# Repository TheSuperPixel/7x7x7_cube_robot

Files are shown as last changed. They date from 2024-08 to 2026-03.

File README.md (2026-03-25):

# 7x7x7_cube_robot
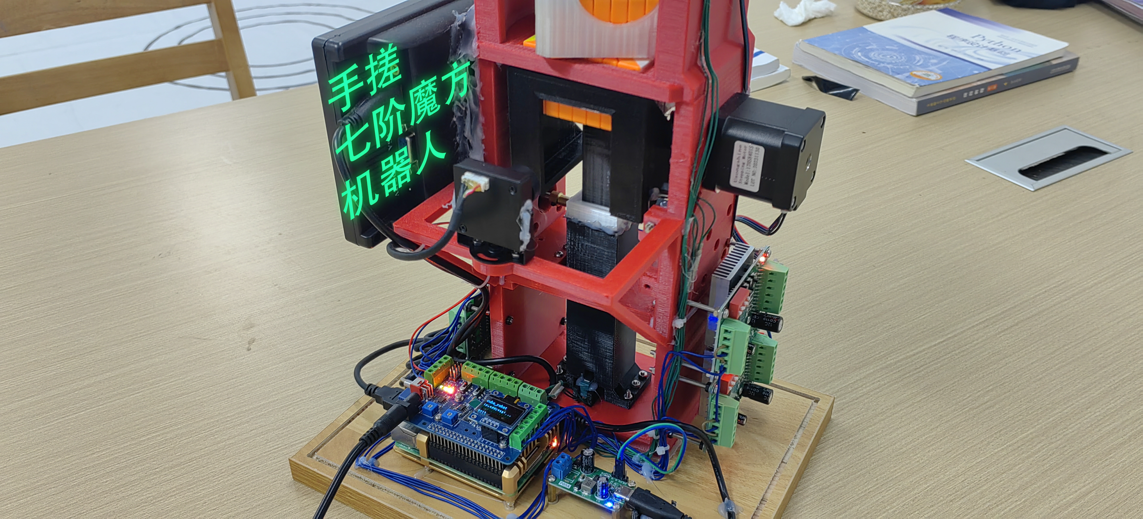
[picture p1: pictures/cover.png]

#### 介绍
使用树莓派控制的魔方机器人，可以在平均20分钟的时间内完成7阶魔方的还原。
这个工程的主要部分复刻了B站“爱跑步的小何”的七阶魔方机器人开源工程，但是在这个工程的基础上，使用了网上开源的CIEDE2000颜色算法识别魔方颜色，提升的颜色识别准确度，另外参照网上开源的OLED程序，额外移植并编写了Linux的OLED、LED和按键的设备驱动，编写了用户菜单界面，使得机器人通电后无需联网、键盘和鼠标，使用按钮进入菜单即可让装置单机还原魔方。<br>
使用C + Python开发，含有结构设计、软件部分，演示视频。推荐使用树莓派4B 4GB，已经通过测试<br>
工程代码添加了部分注释，有些是当时在阅读项目原作者代码时留下来的笔记，因为本人只是电子类大二的学生，Python，Linux，Opencv，Pcb等全部都是提前自学的，项目难免会有缺陷和问题，如果项目出现运行错误，可以参考项目原作者和参考开源项目的readme文件，期待大佬们的宝贵建议
#### 项目主要参考开源资料：
1.七阶魔方机器人源程序：https://gitee.com/hemn1990/cube_robot_7x7x7<br>
2.qbr颜色识别：https://github.com/kkoomen/qbr<br>
3.高阶魔方求解算法：https://github.com/dwalton76/rubiks-cube-NxNxN-solver<br>
4.三阶魔方求解算法：https://github.com/dwalton76/kociemba<br>
5.OLED程序：https://gitee.com/oldzhai/stc89c51/tree/master/oled_i2c

#### 系统架构
```
12V电源--12V转5V电源模块--树莓派--+--步进电机驱动器(TB6560)--升降控制电机(42步进电机)
                                +--升降零点微动开关
                                |
                                +--步进电机驱动器(TB6560)--翻转控制电机(42步进电机)
                                +--翻转零点光电开关
                                |
                                +--步进电机驱动器(TB6560)--旋转控制电机(42步进电机)	
                                +--旋转零点光电开关
                                |
                                +--OLED显示屏，五向摇杆开关(用于脱机运行，OLED显示菜单，摇杆开关用于切换功能)
                                |
                                +--USB摄像头（120度视角）
                                +--键盘、鼠标、显示器
```                         

#### 演示视频：
【树莓派自制支持离线单机复原七阶魔方机器人】 https://www.bilibili.com/video/BV1At42157M8

#### 配置与运行步骤：
1、克隆项目到/home/pi/Desktop/,这个项目里面的文件编译链接，Makefile编写是使用绝对路径的，因此项目运行的路径是被固定的

2、安装python3-opencv
``` 
sudo apt-get install python3-opencv
```
3、安装ckociemba
``` 
cd cube_project\kociemba-develop\kociemba\ckociemba
make clean
make
sudo make install
``` 
3、安装rubiks-cube-NxNxN-solver（该版本相对于原始版本有修改，通过文件流把求解结果传送到cube_robot_motion.py进行运行）
``` 
cd \cube_project\rubiks-cube-NxNxN-solver-master
make clean
make init
./rubiks-cube-solver.py --state DBDBDDFBDDLUBDLFRFRBRLLDUFFDUFRBRDFDRUFDFDRDBDBULDBDBDBUFBUFFFULLFLDURRBBRRBRLFUUUDUURBRDUUURFFFLRFLRLDLBUFRLDLDFLLFBDFUFRFFUUUFURDRFULBRFURRBUDDRBDLLRLDLLDLUURFRFBUBURBRUDBDDLRBULBULUBDBBUDRBLFFBLRBURRUFULBRLFDUFDDBULBRLBUFULUDDLLDFRDRDBBFBUBBFLFFRRUFFRLRRDRULLLFRLFULBLLBBBLDFDBRBFDULLULRFDBR
``` 
第二个步骤很慢，需要联网下载大量查找表，解压后需要占用数G空间。

4、编译并且加载内核模块，在此之前请安装好linux内核头文件，安装位置可参照Makefile
``` 
cd cube_project\cube_robot_7x7x7-master\cube_robot_kernel_module
make clean
make
sudo make load
cd ..
``` 
如需调整电机旋转速度，修改step_moter.py，make table后重新编译内核模块

6、运行主程序
``` 
cd cube_project
sudo run.sh
``` 
1.由于lunch.py使用了subprocess来获取IP信息并且打印在OLED屏幕上，因此如果设备未联网，可能会造成程序卡死或报错，如果无网络，可以将获取IP信息的代码注释，即可正常运行<br>
2.运行后，OLED屏幕会显示菜单，使用五向开关来移动光标和选择选项。在主菜单中，选择“Solve!”进入还原模式，等待出现预览画面后，放入魔方，向右推动摇杆或按下空格键开始还原魔方，向上推动摇杆或按下键盘的'c'键开始进行魔方颜色校准，在校准模式下，向下推动摇杆或按下键盘的空格键校准下一个面的颜色。<br>
3.魔方在转动过程中可能会出现卡顿现象，魔方可能会掉出，需要用手推回去，推测可能是因为3D打印结构缺陷引起<br>
4.魔方颜色识别阈值信息被存储在/home/pi/.config/qbr/settings.json内，如果报错“找不到此文件”，可以尝试在同目录下创建一个同名空文件

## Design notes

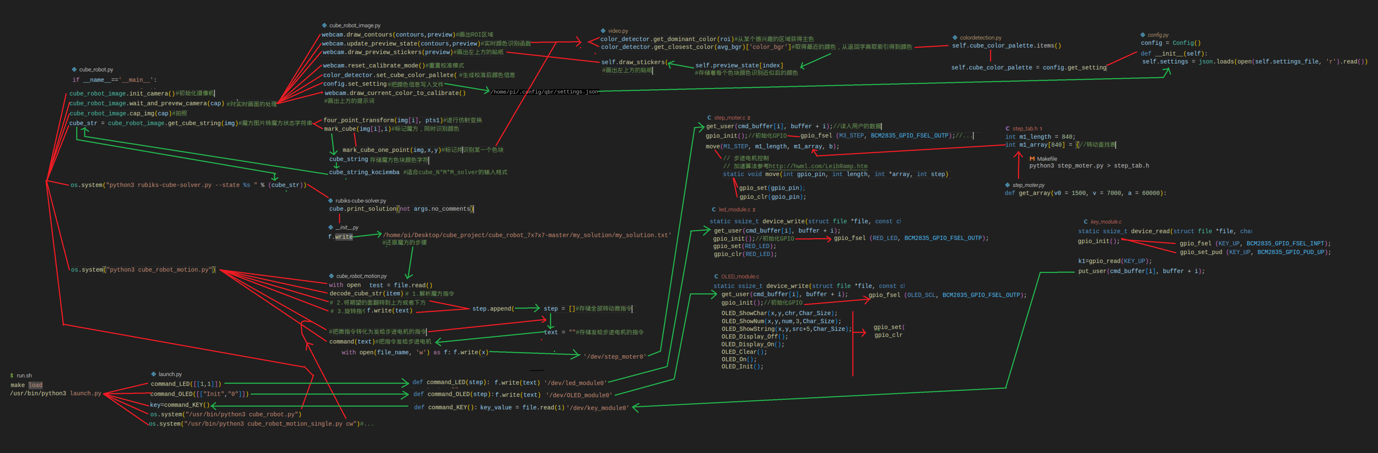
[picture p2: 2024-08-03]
七阶魔方机器人代码框图.png

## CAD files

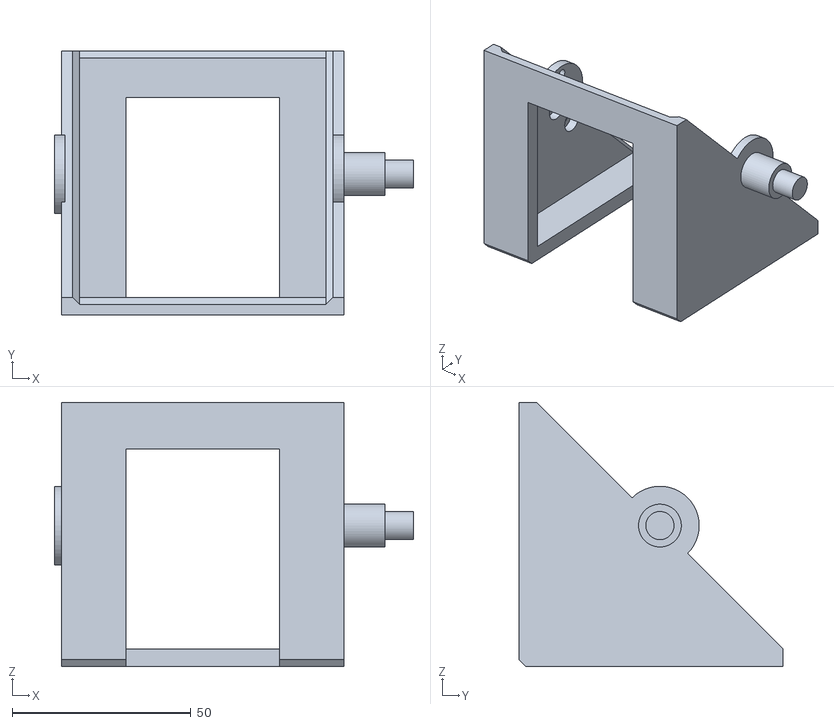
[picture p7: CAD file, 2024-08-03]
结构图/翻转架修改.STL
100.5 x 74.0 x 74.0

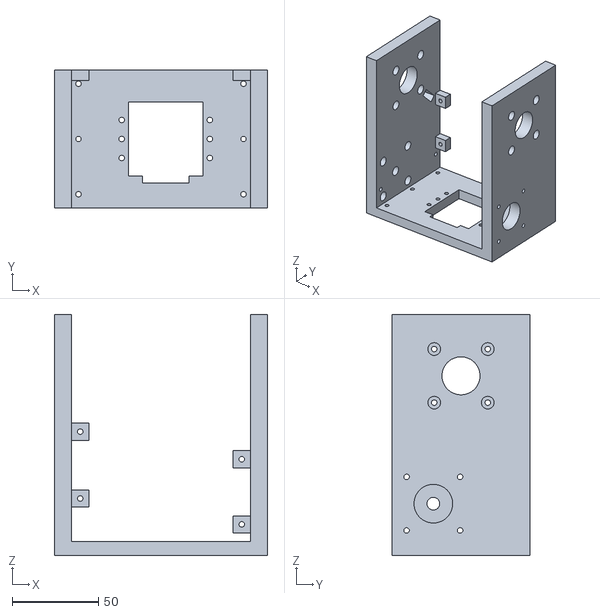
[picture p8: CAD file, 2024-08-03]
结构图/上层框架partA.STL
123.5 x 80.0 x 139.5

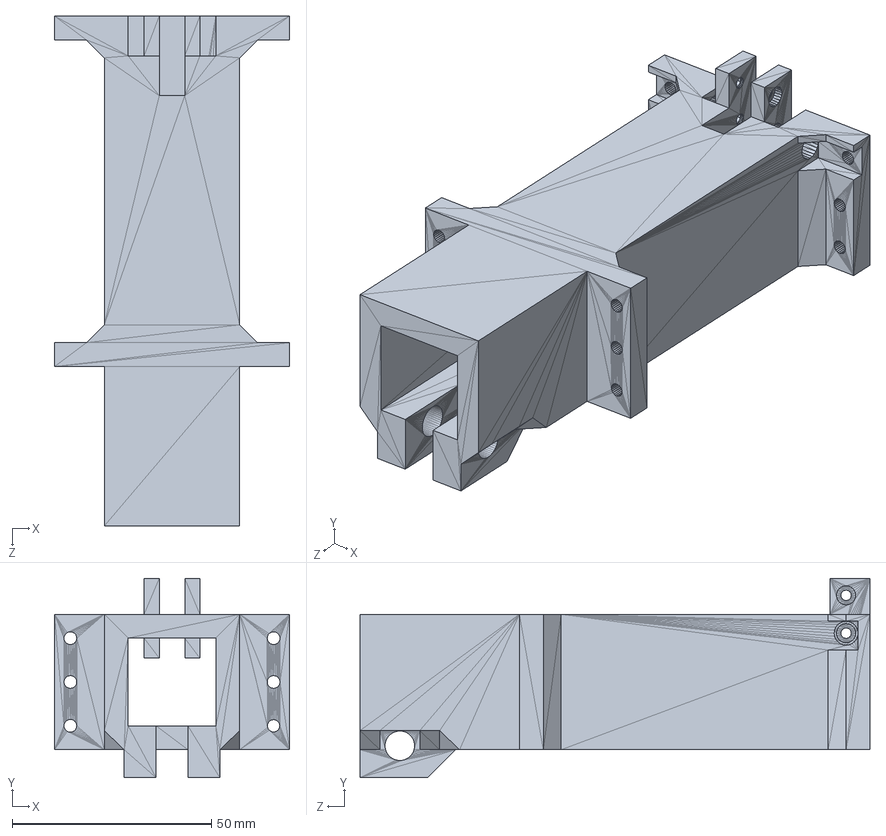
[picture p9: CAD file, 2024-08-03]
结构图/升降杆套筒.SLDPRT
59.0 x 50.0 x 128.0 mm

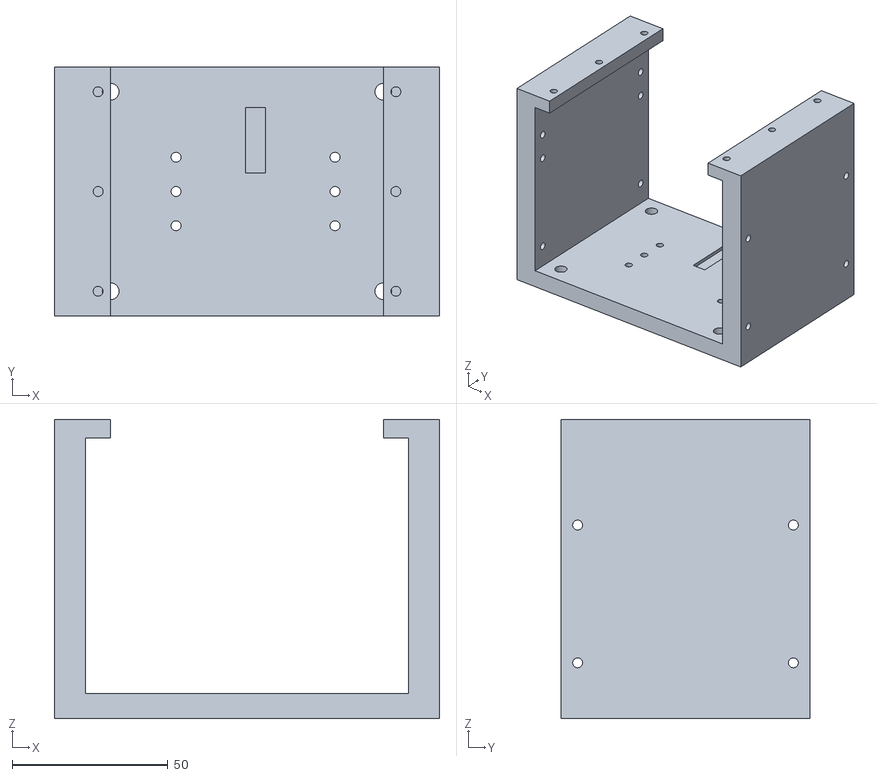
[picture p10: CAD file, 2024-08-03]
结构图/下层框架.stl
123.5 x 80.0 x 96.0

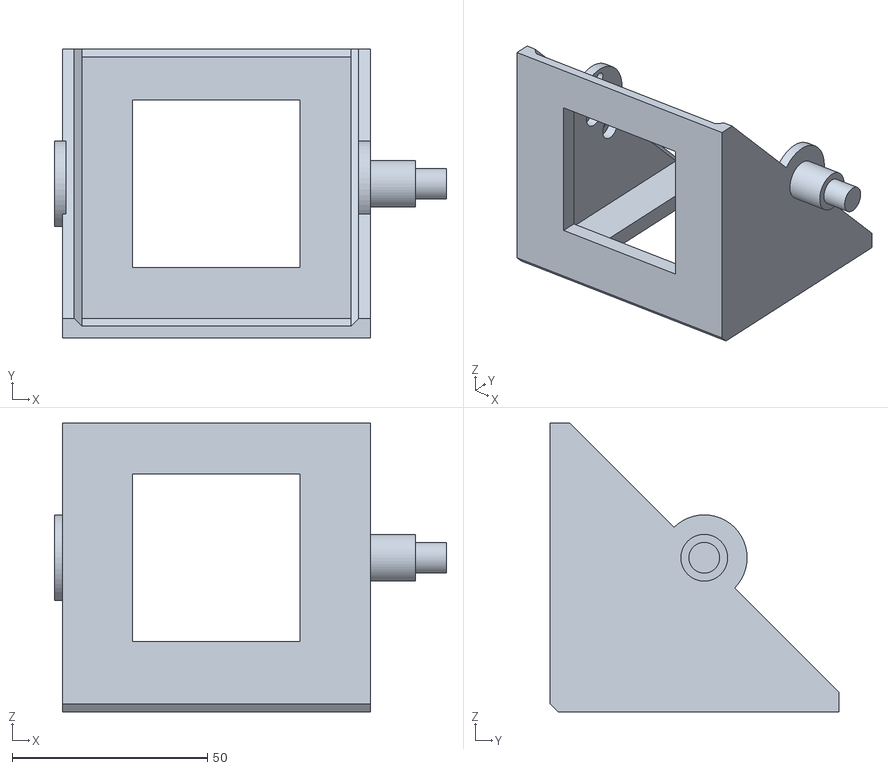
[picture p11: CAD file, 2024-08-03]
结构图/翻转架.stl
100.5 x 74.0 x 74.0

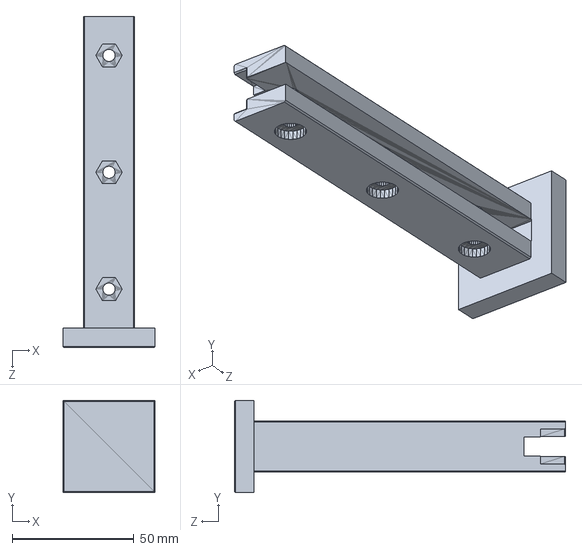
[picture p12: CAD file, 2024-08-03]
结构图/升降杆_打磨.SLDPRT
38.0 x 38.0 x 136.0 mm

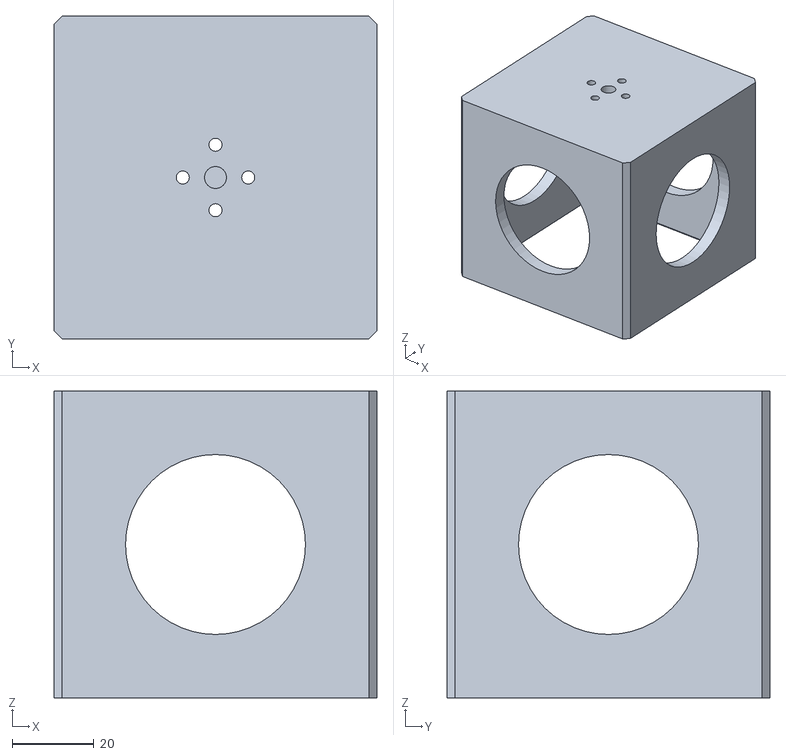
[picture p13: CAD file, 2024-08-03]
结构图/魔方笼.stl
79.0 x 79.0 x 75.0

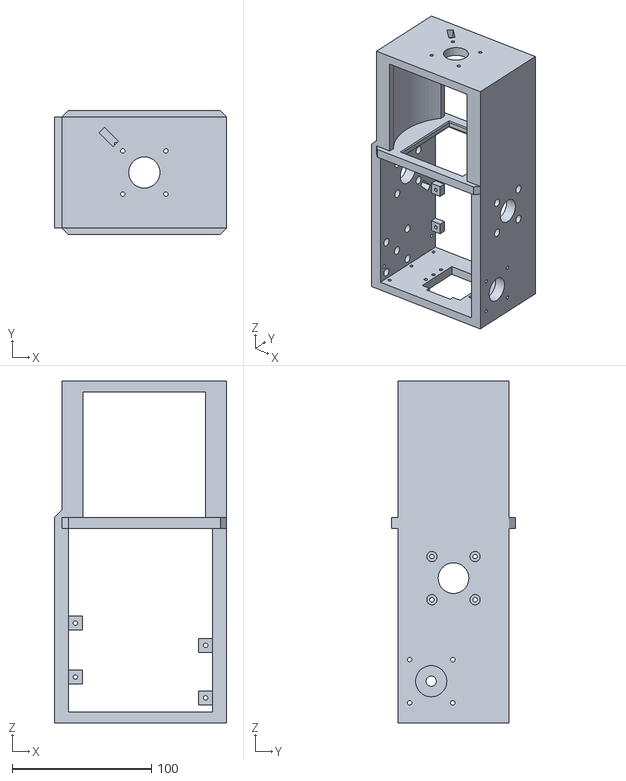
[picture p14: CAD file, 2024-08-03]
结构图/上层框架.stl
123.5 x 89.0 x 245.5

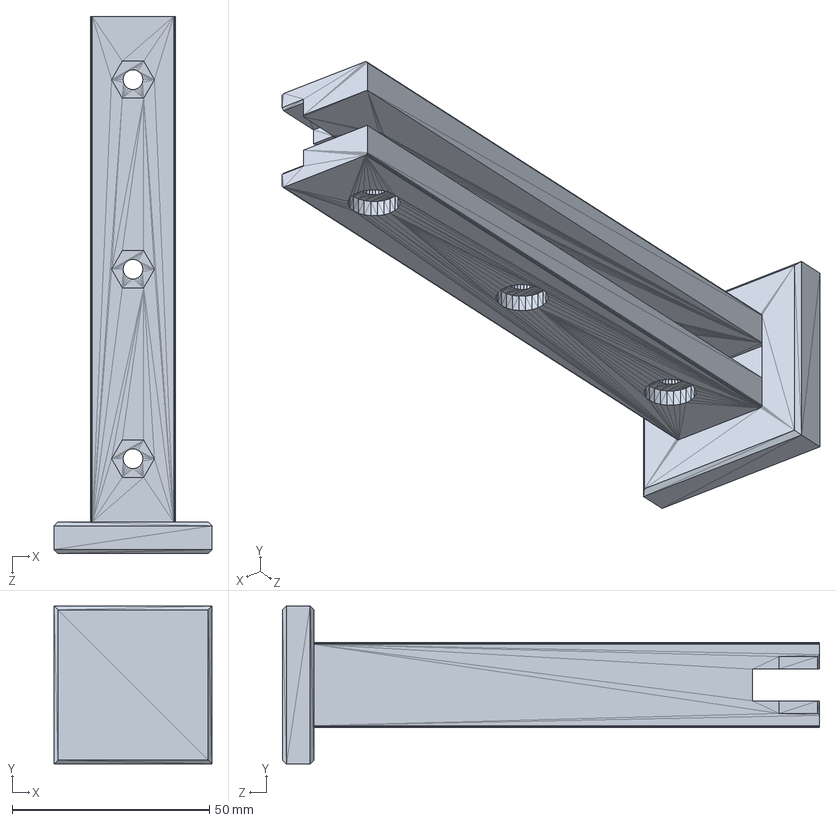
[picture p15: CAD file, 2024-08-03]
结构图/升降杆.SLDPRT
40.0 x 40.0 x 136.0 mm

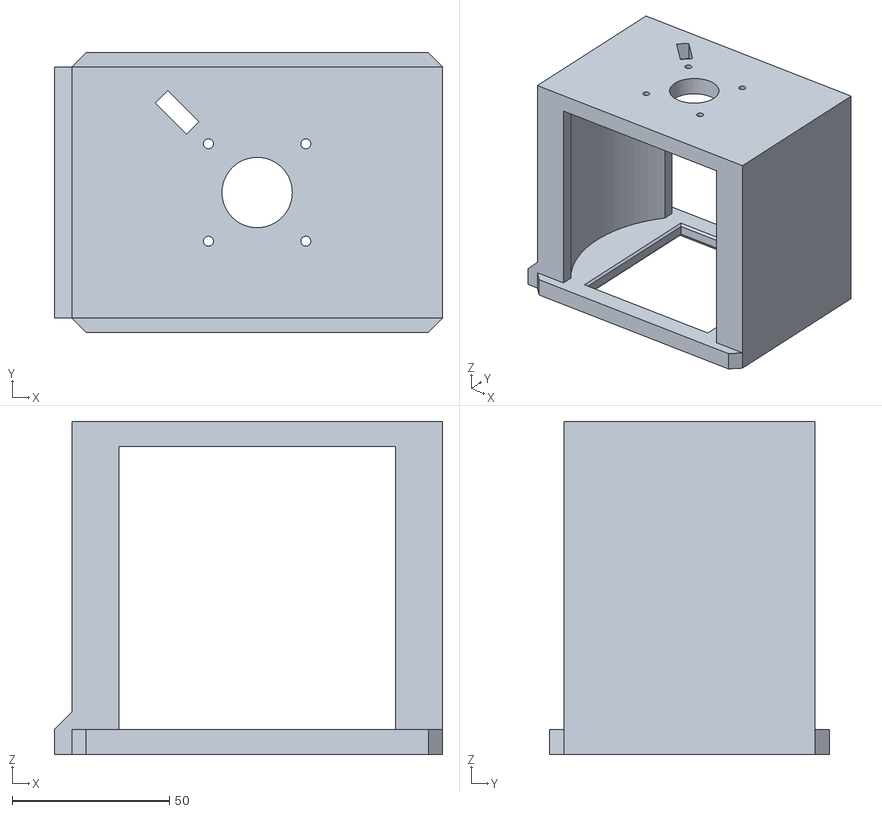
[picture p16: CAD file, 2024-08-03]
结构图/上层框架partB.STL
123.5 x 89.0 x 106.0

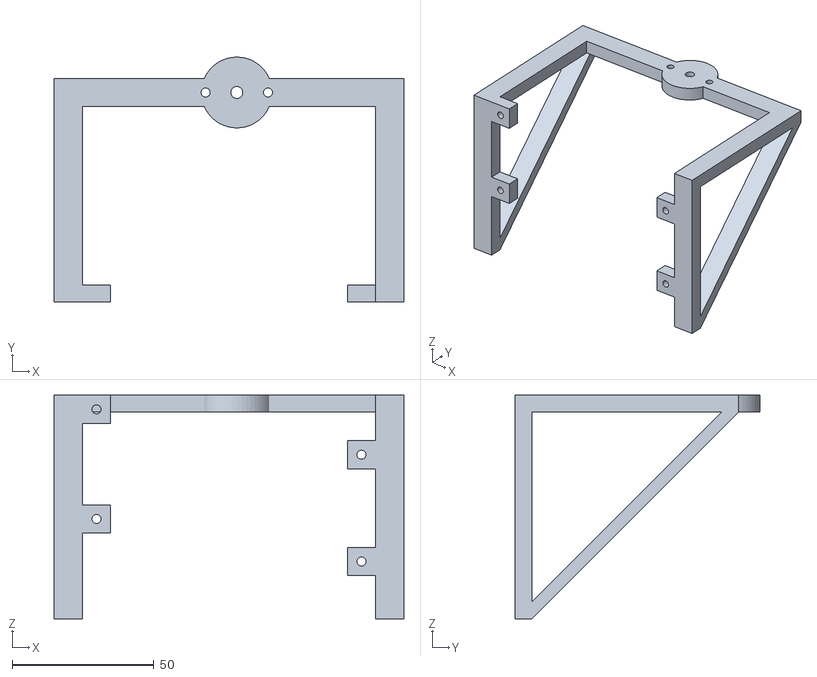
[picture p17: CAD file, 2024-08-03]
结构图/摄像头支架.stl
123.5 x 86.4 x 78.9

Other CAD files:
结构图/升降杆.stl
结构图/升降杆_打磨.STL
结构图/升降杆套筒.stl
结构图/魔方机器人（七阶）.skp

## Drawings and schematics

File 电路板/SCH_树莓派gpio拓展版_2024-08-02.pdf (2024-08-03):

# U4.1 GND ³.3V

# U6.1 GND ³.3V

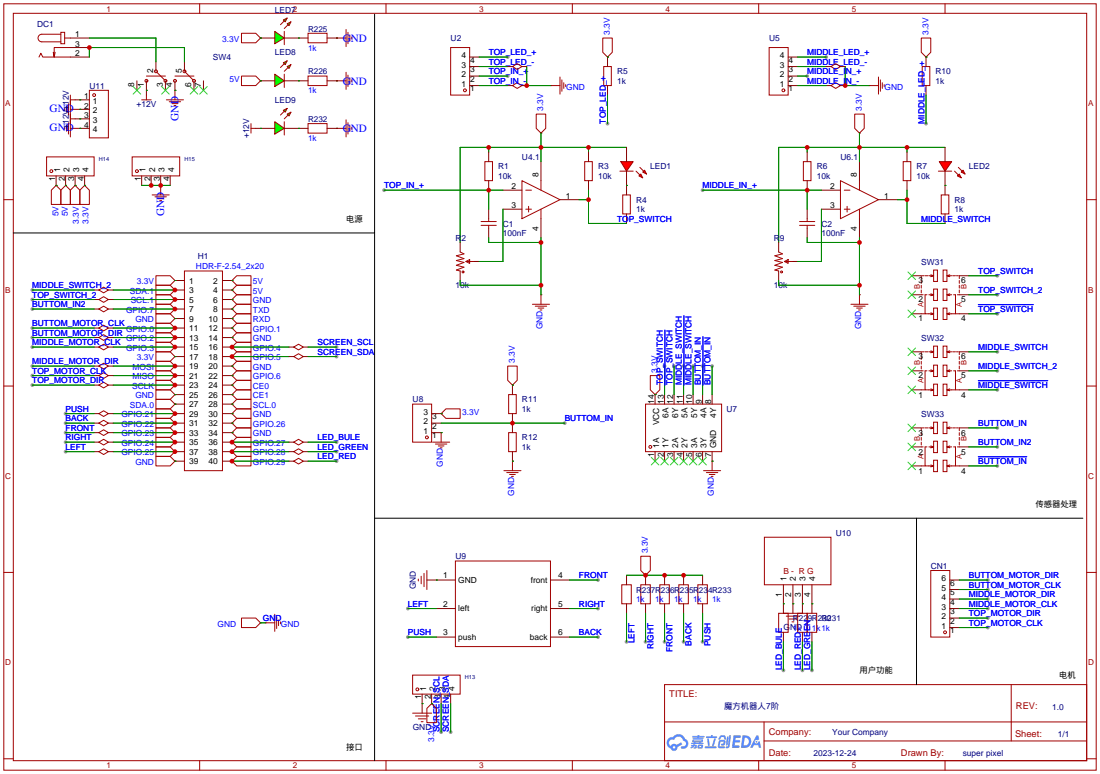
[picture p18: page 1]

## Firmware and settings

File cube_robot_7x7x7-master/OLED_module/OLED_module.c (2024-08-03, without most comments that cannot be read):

#include <linux/module.h>
#include <linux/kernel.h>
#include <linux/init.h>
#include <asm/delay.h>
#include <asm/io.h>
//#include <linux/slab.h> 
#include <linux/fs.h>
#include <asm/uaccess.h>    /* for put_user */
#include <linux/cdev.h>
#include <linux/errno.h>
#include <asm/current.h>
#include <linux/sched.h>
#include <linux/device.h>

#include "OLED_module.h"
#include "oledfont.h"
MODULE_LICENSE("GPL"); 
MODULE_VERSION("0.1"); 
/*
输入：   command,data

command			data
-------------------------------------------------------------------------			
ShowChar		格式：xxyyzw	x：x坐标 y：y坐标 z：字符 w：字体大小 0/1
ShowNum			格式：xxyyzzzw	x：x坐标 y：y坐标 zzz：三位数 w：字体大小 0/1
ShowString		格式：xxyywsss...		x：x坐标 y：y坐标 w：字体大小 0/1 s:字符串
ShowCHinese		不支持
DrawBMP			不支持
DisplayOff		0
DisplayOn		0
Clear			0
On				0
Init			0
*/
static uint32_t* gpio_base = 0;

/* Read input pin */
static uint8_t gpio_read(uint8_t pin)
{
    volatile uint32_t* paddr = gpio_base + BCM2835_GPLEV0/4 + pin/32;
    uint8_t shift = pin % 32;
    uint32_t value = ioread32(paddr);
    return (value & (1 << shift)) ? HIGH : LOW;
}

/* Set output pin */
static void gpio_set(uint8_t pin)
{
    volatile uint32_t* paddr = gpio_base + BCM2835_GPSET0/4 + pin/32;
    uint8_t shift = pin % 32;
    iowrite32(1 << shift, paddr);
}

/* Clear output pin */
static void gpio_clr(uint8_t pin)
{
    volatile uint32_t* paddr = gpio_base + BCM2835_GPCLR0/4 + pin/32;
    uint8_t shift = pin % 32;
    iowrite32(1 << shift, paddr);
}

/* Set the pullup/down resistor for a pin */
static void gpio_set_pud(uint8_t pin, uint8_t pud)
{
        int shiftbits = (pin & 0xf) << 1;
        uint32_t bits;
        uint32_t pull;
        volatile uint32_t* paddr;
        switch (pud)
        {
           case BCM2835_GPIO_PUD_OFF:  pull = 0; break;
           case BCM2835_GPIO_PUD_UP:   pull = 1; break;
           case BCM2835_GPIO_PUD_DOWN: pull = 2; break;
           default: return;
        }
        paddr = gpio_base + BCM2835_GPPUPPDN0/4 + (pin >> 4);
        
        bits = ioread32( paddr );
        bits &= ~(3 << shiftbits);
        bits |= (pull << shiftbits);
        iowrite32(bits, paddr);
}

/* set gpio input or output mode */
static void gpio_fsel(uint8_t pin, uint8_t mode)
{
    /* Function selects are 10 pins per 32 bit word, 3 bits per pin */
    volatile uint32_t* paddr = gpio_base + BCM2835_GPFSEL0/4 + (pin/10);
    uint8_t   shift = (pin % 10) * 3;
    uint32_t  mask = BCM2835_GPIO_FSEL_MASK << shift;
    uint32_t  value = mode << shift;
    
    uint32_t v = ioread32(paddr);
    v = (v & ~mask) | (value & mask);
    iowrite32(v, paddr);
}

void OLED_SCLK_Set(void){
	gpio_set(OLED_SCL);
	udelay(1);
}
void OLED_SCLK_Clr(void){
	gpio_clr(OLED_SCL);
	udelay(1);
}
void OLED_SDIN_Clr(void){
	gpio_clr(OLED_SDA);
	udelay(1);
}
void OLED_SDIN_Set(void){
	gpio_set(OLED_SDA);
	udelay(1);
}
/***********************Delay****************************************/
void Delay_50ms(unsigned int Del_50ms)
{
	unsigned int m;
	for(m=0;m<50;m++){
		udelay(1000);
	}
}

void Delay_1ms(unsigned int Del_1ms)
{
	udelay(1000);
}


/**********************************************
//IIC Start
**********************************************/
void IIC_Start(void)
{
	OLED_SCLK_Set() ;
	OLED_SDIN_Set();
	OLED_SDIN_Clr();
	OLED_SCLK_Clr();
}

/**********************************************
//IIC Stop
**********************************************/
void IIC_Stop(void)
{
	OLED_SCLK_Set() ;
	OLED_SDIN_Clr();
	OLED_SDIN_Set();
}

void IIC_Wait_Ack(void)
{
	OLED_SCLK_Set() ;
	OLED_SCLK_Clr();
}
/**********************************************
// IIC Write byte
**********************************************/

void Write_IIC_Byte(unsigned char IIC_Byte)
{
	unsigned char i;
	unsigned char m,da;
	da=IIC_Byte;
	OLED_SCLK_Clr();
	for(i=0;i<8;i++)		
	{
			m=da;
		//	OLED_SCLK_Clr();
		m=m&0x80;
		if(m==0x80)
		{OLED_SDIN_Set();}
		else OLED_SDIN_Clr();
			da=da<<1;
		OLED_SCLK_Set();
		OLED_SCLK_Clr();
		}
}

/**********************************************
// IIC Write Command
**********************************************/
void Write_IIC_Command(unsigned char IIC_Command)
{
   IIC_Start();
   Write_IIC_Byte(0x78);            //Slave address,SA0=0
	IIC_Wait_Ack();	
   Write_IIC_Byte(0x00);			//write command
	IIC_Wait_Ack();	
   Write_IIC_Byte(IIC_Command); 
	IIC_Wait_Ack();	
   IIC_Stop();
}
/**********************************************
// IIC Write Data
**********************************************/
void Write_IIC_Data(unsigned char IIC_Data)
{
   IIC_Start();
   Write_IIC_Byte(0x78);			//D/C#=0; R/W#=0
	 IIC_Wait_Ack();	
   Write_IIC_Byte(0x40);			//write data
	 IIC_Wait_Ack();	
   Write_IIC_Byte(IIC_Data);
	 IIC_Wait_Ack();	
   IIC_Stop();
}
void OLED_WR_Byte(unsigned dat,unsigned cmd)
{
	if(cmd)
	{
		Write_IIC_Data(dat);
	}
	else 
	{	
		Write_IIC_Command(dat);
	}
}

/********************************************
// fill_Picture
********************************************/
void fill_picture(unsigned char fill_Data)
{
	unsigned char m,n;
	for(m=0;m<8;m++)
	{
		OLED_WR_Byte(0xb0+m,0);		//page0-page1
		OLED_WR_Byte(0x00,0);		//low column start address
		OLED_WR_Byte(0x10,0);		//high column start address
		for(n=0;n<128;n++)
			{
				OLED_WR_Byte(fill_Data,1);
			}
	}
}



void OLED_Set_Pos(unsigned char x, unsigned char y) 
{ 	OLED_WR_Byte(0xb0+y,OLED_CMD);
	OLED_WR_Byte(((x&0xf0)>>4)|0x10,OLED_CMD);
	OLED_WR_Byte((x&0x0f),OLED_CMD); 
} 


void OLED_Display_On(void)
{
	OLED_WR_Byte(0X8D,OLED_CMD);
	OLED_WR_Byte(0X14,OLED_CMD);  //DCDC ON
	OLED_WR_Byte(0XAF,OLED_CMD);  //DISPLAY ON
}


void OLED_Display_Off(void)
{
	OLED_WR_Byte(0X8D,OLED_CMD);
	OLED_WR_Byte(0X10,OLED_CMD);  //DCDC OFF
	OLED_WR_Byte(0XAE,OLED_CMD);  //DISPLAY OFF
}


void OLED_Clear(void)  
{  
	u8 i,n;		    
	for(i=0;i<8;i++)  
	{  
		OLED_WR_Byte (0xb0+i,OLED_CMD);
		OLED_WR_Byte (0x00,OLED_CMD);
		OLED_WR_Byte (0x10,OLED_CMD);
		for(n=0;n<128;n++)OLED_WR_Byte(0,OLED_DATA); 
	}
}

void OLED_On(void)  
{  
	u8 i,n;		    
	for(i=0;i<8;i++)  
	{  
		OLED_WR_Byte (0xb0+i,OLED_CMD);
		OLED_WR_Byte (0x00,OLED_CMD);
		OLED_WR_Byte (0x10,OLED_CMD);
		for(n=0;n<128;n++)OLED_WR_Byte(1,OLED_DATA); 
	}
}


//x:0~127
//y:0~63


void OLED_ShowChar(u8 x,u8 y,u8 chr,u8 Char_Size)
{      	
	unsigned char c=0,i=0;	
		c=chr-' ';
		if(x>Max_Column-1){x=0;y=y+2;}
		if(Char_Size ==16)
			{
			OLED_Set_Pos(x,y);	
			for(i=0;i<8;i++)
			OLED_WR_Byte(F8X16[c*16+i],OLED_DATA);
			OLED_Set_Pos(x,y+1);
			for(i=0;i<8;i++)
			OLED_WR_Byte(F8X16[c*16+i+8],OLED_DATA);
			}
			else {	
				OLED_Set_Pos(x,y);
				for(i=0;i<6;i++)
				OLED_WR_Byte(F6x8[c][i],OLED_DATA);
				
			}
}


u32 oled_pow(u8 m,u8 n)
{
	u32 result=1;	 
	while(n--)result*=m;    
	return result;
}
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

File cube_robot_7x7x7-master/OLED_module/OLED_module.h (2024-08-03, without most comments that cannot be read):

#ifndef __OLED_H__
#define __OLED_H__			  	 

#define OLED_SCL      23 //16pin
#define OLED_SDA     24 //18pin

#define  u8 unsigned char 
#define  u32 unsigned int 
#define OLED_CMD  0
#define OLED_DATA 1
#define OLED_MODE 0








#define SIZE 16
#define XLevelL		0x02
#define XLevelH		0x10
#define Max_Column	128
#define Max_Row		64
#define	Brightness	0xFF 
#define X_WIDTH 	128
#define Y_WIDTH 	64	    

//*********************************************************************************
// GPIO控制器地址,参考/proc/iomem
#define RPI4_GPIO_ADDR 0xfe200000
#define RPI4_GPIO_SIZE 256

/*! This means pin HIGH, true, 3.3volts on a pin. */
#define HIGH 0x1
/*! This means pin LOW, false, 0volts on a pin. */
#define LOW  0x0

/* Defines for GPIO
   The BCM2835 has 54 GPIO pins.
   BCM2835 data sheet, Page 90 onwards.
*/
/*! GPIO register offsets from BCM2835_GPIO_BASE. 
  Offsets into the GPIO Peripheral block in bytes per 6.1 Register View 
*/
#define BCM2835_GPFSEL0                      0x0000 /*!< GPIO Function Select 0 */
#define BCM2835_GPFSEL1                      0x0004 /*!< GPIO Function Select 1 */
#define BCM2835_GPFSEL2                      0x0008 /*!< GPIO Function Select 2 */
#define BCM2835_GPFSEL3                      0x000c /*!< GPIO Function Select 3 */
#define BCM2835_GPFSEL4                      0x0010 /*!< GPIO Function Select 4 */
#define BCM2835_GPFSEL5                      0x0014 /*!< GPIO Function Select 5 */
#define BCM2835_GPSET0                       0x001c /*!< GPIO Pin Output Set 0 */
#define BCM2835_GPSET1                       0x0020 /*!< GPIO Pin Output Set 1 */
#define BCM2835_GPCLR0                       0x0028 /*!< GPIO Pin Output Clear 0 */
#define BCM2835_GPCLR1                       0x002c /*!< GPIO Pin Output Clear 1 */
#define BCM2835_GPLEV0                       0x0034 /*!< GPIO Pin Level 0 */
#define BCM2835_GPLEV1                       0x0038 /*!< GPIO Pin Level 1 */
#define BCM2835_GPEDS0                       0x0040 /*!< GPIO Pin Event Detect Status 0 */
#define BCM2835_GPEDS1                       0x0044 /*!< GPIO Pin Event Detect Status 1 */
#define BCM2835_GPREN0                       0x004c /*!< GPIO Pin Rising Edge Detect Enable 0 */
#define BCM2835_GPREN1                       0x0050 /*!< GPIO Pin Rising Edge Detect Enable 1 */
#define BCM2835_GPFEN0                       0x0058 /*!< GPIO Pin Falling Edge Detect Enable 0 */
#define BCM2835_GPFEN1                       0x005c /*!< GPIO Pin Falling Edge Detect Enable 1 */
#define BCM2835_GPHEN0                       0x0064 /*!< GPIO Pin High Detect Enable 0 */
#define BCM2835_GPHEN1                       0x0068 /*!< GPIO Pin High Detect Enable 1 */
#define BCM2835_GPLEN0                       0x0070 /*!< GPIO Pin Low Detect Enable 0 */
#define BCM2835_GPLEN1                       0x0074 /*!< GPIO Pin Low Detect Enable 1 */
#define BCM2835_GPAREN0                      0x007c /*!< GPIO Pin Async. Rising Edge Detect 0 */
#define BCM2835_GPAREN1                      0x0080 /*!< GPIO Pin Async. Rising Edge Detect 1 */
#define BCM2835_GPAFEN0                      0x0088 /*!< GPIO Pin Async. Falling Edge Detect 0 */
#define BCM2835_GPAFEN1                      0x008c /*!< GPIO Pin Async. Falling Edge Detect 1 */
#define BCM2835_GPPUD                        0x0094 /*!< GPIO Pin Pull-up/down Enable */
#define BCM2835_GPPUDCLK0                    0x0098 /*!< GPIO Pin Pull-up/down Enable Clock 0 */
#define BCM2835_GPPUDCLK1                    0x009c /*!< GPIO Pin Pull-up/down Enable Clock 1 */

/* 2711 has a different method for pin pull-up/down/enable  */
#define BCM2835_GPPUPPDN0                    0x00e4 /* Pin pull-up/down for pins 15:0  */
#define BCM2835_GPPUPPDN1                    0x00e8 /* Pin pull-up/down for pins 31:16 */
#define BCM2835_GPPUPPDN2                    0x00ec /* Pin pull-up/down for pins 47:32 */
#define BCM2835_GPPUPPDN3                    0x00f0 /* Pin pull-up/down for pins 57:48 */

/*!   \brief bcm2835PortFunction
  Port function select modes for bcm2835_gpio_fsel()
*/
typedef enum
{
    BCM2835_GPIO_FSEL_INPT  = 0x00,   /*!< Input 0b000 */
    BCM2835_GPIO_FSEL_OUTP  = 0x01,   /*!< Output 0b001 */
    BCM2835_GPIO_FSEL_ALT0  = 0x04,   /*!< Alternate function 0 0b100 */
    BCM2835_GPIO_FSEL_ALT1  = 0x05,   /*!< Alternate function 1 0b101 */
    BCM2835_GPIO_FSEL_ALT2  = 0x06,   /*!< Alternate function 2 0b110, */
    BCM2835_GPIO_FSEL_ALT3  = 0x07,   /*!< Alternate function 3 0b111 */
    BCM2835_GPIO_FSEL_ALT4  = 0x03,   /*!< Alternate function 4 0b011 */
    BCM2835_GPIO_FSEL_ALT5  = 0x02,   /*!< Alternate function 5 0b010 */
    BCM2835_GPIO_FSEL_MASK  = 0x07    /*!< Function select bits mask 0b111 */
} bcm2835FunctionSelect;

/*! \brief bcm2835PUDControl
  Pullup/Pulldown defines for bcm2835_gpio_pud()
*/
typedef enum
{
    BCM2835_GPIO_PUD_OFF     = 0x00,   /*!< Off ? disable pull-up/down 0b00 */
    BCM2835_GPIO_PUD_DOWN    = 0x01,   /*!< Enable Pull Down control 0b01 */
    BCM2835_GPIO_PUD_UP      = 0x02    /*!< Enable Pull Up control 0b10  */
} bcm2835PUDControl;

#endif  
	 
